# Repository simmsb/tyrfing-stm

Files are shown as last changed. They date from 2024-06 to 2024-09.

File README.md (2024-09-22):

# Hardware and firmware for my flashlight drivers that use stm32L0 processors

<p float="left" align="middle">
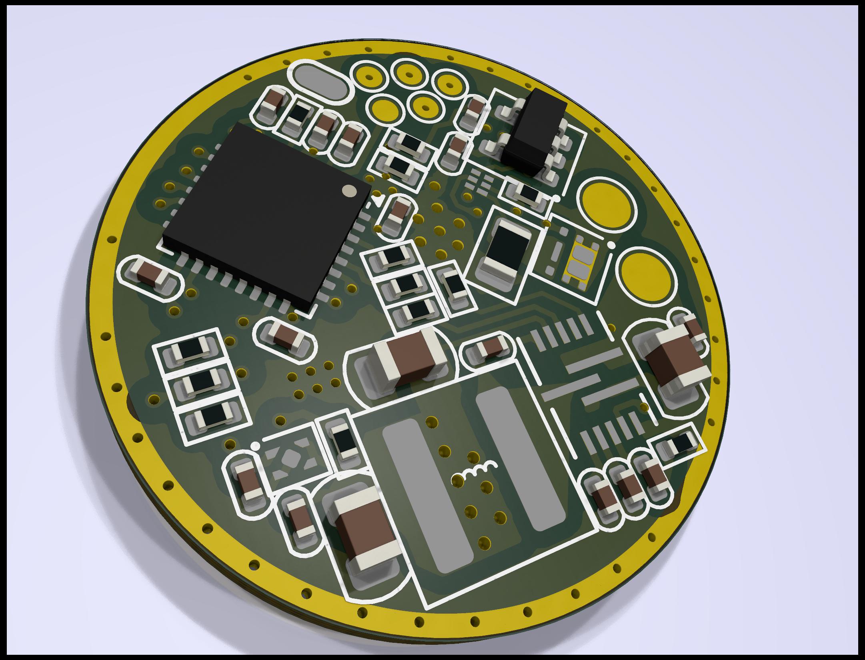
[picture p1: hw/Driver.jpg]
  
  
  
</p>

This repo contains the KiCad files of my self-designed flashlight driver (stm32L0, using a MP3432 boost driver) and the Rust firmware for it.

Mostly based off my [AVR flashlight firmware](https://github.com/simmsb/tyrfing/), also written in Rust.

# Running and flashing

To run with debug logging: `env DEFMT_LOG="debug" cargo run`
To flash a non-debug build: `env DEFMT_LOG="off" cargo run --no-default-features --features default_no_debug --release`

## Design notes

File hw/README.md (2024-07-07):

# Hardware stuff

This folder contains the kicad schematic and layout for the driver, and
`boost.nbt` which is all the potential divider calculations, written in
[numbat](https://github.com/sharkdp/numbat).

# Changelog

- v0: Initial design: had the mistake of using the Rds(on) of a FET as a sense
  resistor... that's a bad idea, don't do it.
  
- v1: Second revision: uses a real sense resistor to measure the high end
  current, and an analog mux to switch between measuring before the low end
  sense resistor, or the high end sense resistor (such that we don't measure
  Rds(on) + Rsense).
  
  I also changed the LDO from 2.5v to 2.8v
  
- v2: Third revision: Adds more current return path vias, but makes the spring
  pad off center (I have no idea if this will work)
  
# Issues I think I still have

1. As of v1 I am not completely happy with the current return path after the
   sense resistors, currently there are vias spammed everywhere possible but I'm
   not sure there's enough. With v2 I added more vias and moved the spring pad
   off center, but that sounds dumb.

# Thanks

This video series:
https://www.youtube.com/playlist?list=PLYK5tmZIBWtEJjwAFE-49hSeELu9zoAmV was a
great help with getting started designing the current controlled boost circuit.

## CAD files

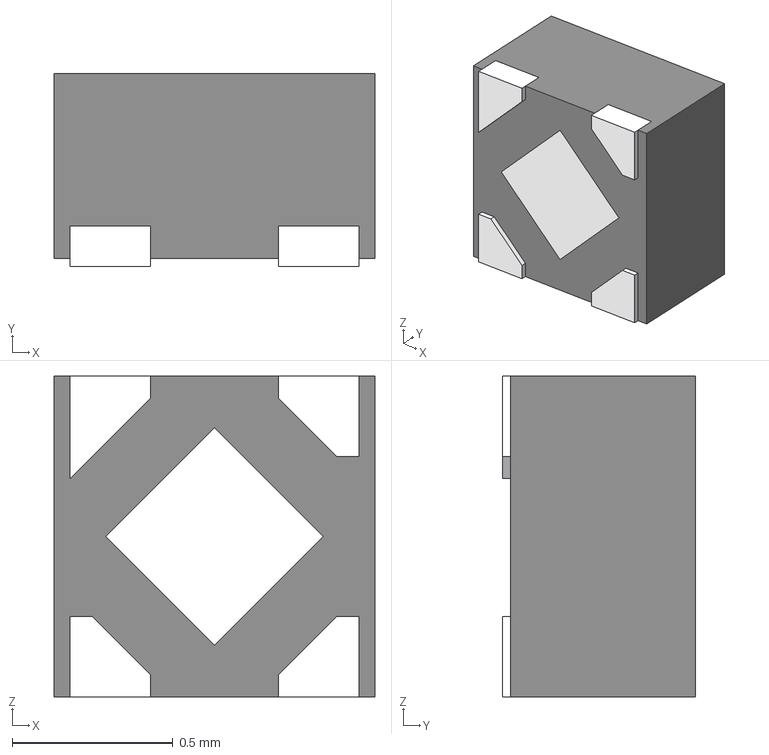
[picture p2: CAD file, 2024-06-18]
hw/components/NCP114AMX330TCG.stp
1.00 x 0.6 x 1.00 mm

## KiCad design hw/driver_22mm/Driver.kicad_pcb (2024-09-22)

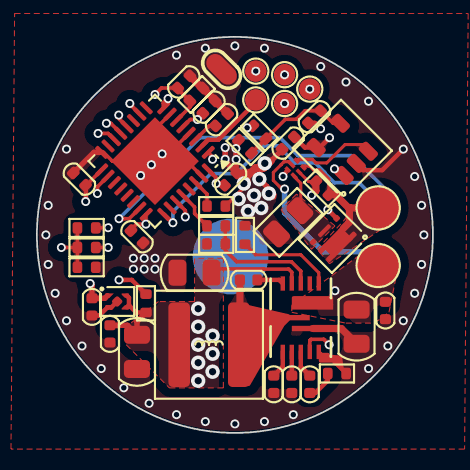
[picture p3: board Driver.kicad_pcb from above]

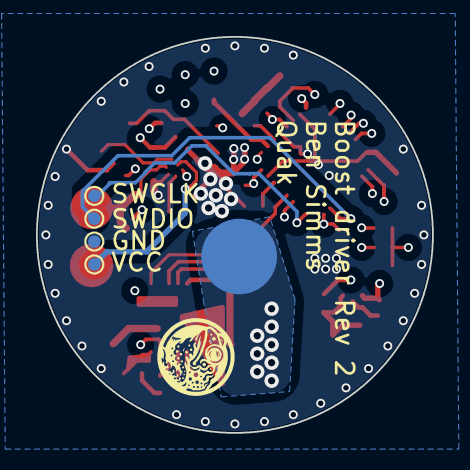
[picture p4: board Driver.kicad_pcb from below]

Board: 4 copper layers, 22.0 x 22.0 mm, 51 parts (4 on the bottom side), 33 nets.

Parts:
C1, C3, C13: 47uF; C_0805_2012Metric
C4, C16, C20: 4.7uF; C_0402_1005Metric
C5: 22nF; C_0402_1005Metric
C6, C8, C10, C14, C15, C17, C18: 100nF; C_0402_1005Metric
C7: 3.3nF; C_0402_1005Metric
C9: 6.8nF; C_0402_1005Metric
C19: 10uF; C_0402_1005Metric
C21: 1nF; C_0402_1005Metric
J1: +LED; TestPoint_Pad_D2.0mm
J2: -LED; TestPoint_Pad_D2.0mm
J3: Button LED; TestPoint_Pad_D1.0mm
J4: Wire GND; TestPoint_Pad_D1.0mm_copy
J5: SWDIO; TestPoint_Pad_D0.7mm
J6: SWCLK; TestPoint_Pad_D0.7mm
J7: GND; TestPoint_Pad_D0.7mm
J8: VCC; TestPoint_Pad_D0.7mm
J9: B; TestPoint_Pad_D1.0mm
J10: R; TestPoint_Pad_D1.0mm
J11: G; TestPoint_Pad_D1.0mm
J12: Button; TestPoint_Pad_D1.0mm
L1: 1.3uH; L_Coilcraft_XAL5030
Q1: Vishay_PowerPAK_SC70-6L_Single
R1: 20k - R_UVLO_BOTTOM; R_0402_1005Metric
R2: 24k - R_UVLO_BOTTOM; R_0402_1005Metric
R3: 285k - R_DAC_TOP; R_0402_1005Metric
R4: 3.3K - R_DAC_BOTTOM1; R_0402_1005Metric
R5: 10m - R_SENSE_MAIN; R_0805_2012Metric
R6: 4R - R_SENSE_HDR; R_0402_1005Metric
R7: 27k; R_0402_1005Metric
R8: 6.8k; R_0402_1005Metric
R9: 750k - R_FB_A; R_0402_1005Metric
R10: 75k - R_FB_B; R_0402_1005Metric
R11: 434k - R_FB_C; R_0402_1005Metric
R12: 10k; R_0402_1005Metric
R13: 1.6M - R_BAT_TOP; R_0402_1005Metric
R14: 3M - R_BAT_BOT; R_0402_1005Metric
U1: MP3431GL-P; QFN-13_MP3431_MNP
U2: OPA333AIDBV; SOT-23-5
U3: STM32L072KBUx; QFN-32-1EP_5x5mm_P0.5mm_EP3.45x3.45mm
U4: NCP114AMX280TCG; UDFN-4-1EP_1x1mm_P0.65mm_EP0.48x0.48mm
U5: XS3A1T3157GSH; XSON6_SOT1202_NEX

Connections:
+BATT: C1.1, C3.1, C16.1, L1.1, R13.1, U1.12 (VIN), U4.3 (EN), U4.4 (IN)
/-LED: J2.1, Q1.1 (D), R6.1, U5.3 (Y1)
/BAT_SENSE: C21.1, R13.2, R14.1, U3.6 (PA0)
/BOOST_EN: R1.1, U3.28 (PB6)
/DAC: R3.1, U3.10 (PA4)
/FB: R9.2, R10.1, R11.2, U1.5 (FB)
/HDR: Q1.3 (G), U3.8 (PA2)
/OPAMP_EN: C8.2, U2.5 (V+), U3.27 (PB5)
/SHUNT_SELECT: U3.1 (PC14), U5.6 (S)
/SWCLK: J6.1, U3.25 (PA14)
/SWDIO: J5.1, U3.23 (PA13)
GND: C1.2, C3.2, C4.2, C5.2, C8.1, C10.2, C13.2, C14.2, C15.1, C16.2, C17.1, C18.1, C19.1, C20.2, C21.2, J4.1, J7.1, R2.2, R4.2, R5.2, R6.2, R7.2, R8.2, R10.2, R12.2, R14.2, U1.6 (AGND), U1.7 (PGND), U2.2 (V-), U3.4 (VSSA), U3.7 (PA1), U3.16 (VSS), U3.31 (VSS), U3.33 (VSS), U4.2 (GND), U4.5 (GND), U5.2 (GND)
unnamed: C7.2, R11.1, U2.1
unnamed: C9.2, R8.1
unnamed: J3.1, U3.2 (PC15)
unnamed: J9.1, U3.14 (PB0)
unnamed: J10.1, U3.12 (PA6)
unnamed: J11.1, U3.13 (PA7)
unnamed: J12.1, U3.18 (PA8)
unnamed: Q1.4 (S), R5.1, U5.1 (Y2)
unnamed: C6.2, U1.13 (BST)
unnamed: C9.1, U1.4 (COMP)
unnamed: R1.2, R2.1, U1.11 (EN)
unnamed: R7.1, U1.9 (ILIM)
unnamed: C5.1, U1.3 (SS)
unnamed: C6.1, L1.2, U1.1 (SW)
unnamed: C4.1, U1.2 (VDD)
unnamed: U2.3 (+), U5.4 (Z)
unnamed: C7.1, R3.2, R4.1, U2.4 (-)
unnamed: R12.1, U3.30 (BOOT0)
unnamed: C14.1, U3.3 (NRST)
VCC: C15.2, C17.2, C18.2, C19.2, C20.1, J8.1, U3.5 (VDDA), U3.17 (VDD), U3.24 (VDD_USB), U3.32 (VDD), U4.1 (OUT), U5.5 (VCC)
VPP: C10.1, C13.1, J1.1, R9.1, U1.8 (VOUT)

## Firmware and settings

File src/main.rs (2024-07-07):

#![feature(type_alias_impl_trait)]
#![feature(impl_trait_in_assoc_type)]
#![feature(impl_trait_in_fn_trait_return)]
#![feature(async_closure)]
#![no_std]
#![no_main]

use defmt::*;
use embassy_stm32::rtc::{Rtc, RtcConfig};
use portable_atomic::AtomicUsize;
use static_cell::{make_static, StaticCell};
// use static_cell::StaticCell;
#[cfg(not(feature = "debug"))]
use panic_reset as _;
#[cfg(feature = "debug")]
use {defmt_rtt as _, panic_probe as _};

mod aux;
mod battery_level;
mod click;
mod monitoring;
mod pins;
mod power;
mod power_curve;
mod state;
mod ui;

#[cfg(feature = "use_maitake_executor")]
mod executor;

static CNT: AtomicUsize = AtomicUsize::new(0);

defmt::timestamp! {"{}", CNT.fetch_add(1, portable_atomic::Ordering::Relaxed) }

#[cfg(feature = "use_maitake_executor")]
mod maitake_stuff {
    use core::future::Future;

    pub struct StaticStorage;

    impl<S: 'static, F: Future + 'static> maitake::task::Storage<S, F> for StaticStorage {
        type StoredTask = &'static mut maitake::task::Task<S, F, StaticStorage>;

        fn into_raw(task: Self::StoredTask) -> core::ptr::NonNull<maitake::task::Task<S, F, Self>> {
            core::ptr::NonNull::from(task)
        }

        fn from_raw(
            mut ptr: core::ptr::NonNull<maitake::task::Task<S, F, Self>>,
        ) -> Self::StoredTask {
            unsafe { ptr.as_mut() }
        }
    }

    impl StaticStorage {
        pub fn allocate<S: maitake::scheduler::Schedule + 'static, F: Future + 'static>(
            fut: F,
        ) -> maitake::task::Task<S, F, Self> {
            maitake::task::Task::new(fut)
        }
    }

    #[repr(transparent)]
    pub struct SurelySend<T>(pub T);
    unsafe impl<T> Send for SurelySend<T> {}
    impl<T: Future> Future for SurelySend<T> {
        type Output = <T as Future>::Output;

        fn poll(
            self: core::pin::Pin<&mut Self>,
            cx: &mut core::task::Context<'_>,
        ) -> core::task::Poll<Self::Output> {
            unsafe { T::poll(core::mem::transmute(self), cx) }
        }
    }
}

#[cfg(feature = "use_maitake_executor")]
#[cortex_m_rt::entry]
fn main() -> ! {
    use maitake_stuff::*;

    macro_rules! spawn {
        ($f:expr) => {{
            let task = make_static!(StaticStorage::allocate(SurelySend($f)));
            task.bind(crate::executor::scheduler());
            crate::executor::scheduler()
                .build_task()
                .spawn_allocated::<StaticStorage, _>(task)
        }};
    }

    info!("Hello world");

    let cfg = embassy_stm32::Config::default();
    let p = embassy_stm32::init(cfg);
    let rtc = Rtc::new(p.RTC, RtcConfig::default());

    static RTC: StaticCell<Rtc> = StaticCell::new();
    let rtc = RTC.init(rtc);

    spawn!(monitoring::monitoring_task(
        pins::take_battery_sense!(p),
        p.ADC1,
        p.IWDG
    ));
    spawn!(power::power_task(
        pins::take_hdr!(p),
        pins::take_opamp_en!(p),
        pins::take_boost_en!(p),
        pins::take_shunt_select!(p),
        p.DAC1,
        pins::take_dac!(p),
        p.PA5
    ));
    spawn!(aux::aux_task(
        p.TIM3,
        pins::take_aux_r!(p),
        pins::take_aux_g!(p),
        pins::take_aux_b!(p)
    ));
    spawn!(click::debouncer_task(
        pins::take_button!(p),
        p.EXTI8,
        pins::take_button_led!(p)
    ));
    spawn!(click::event_generator_task());
    spawn!(ui::torch_ui_task());

    crate::executor::run(rtc);
}

// TODO(ben) add back in support for using the embassy executor, check binary sizes

// #[embassy_executor::task]
// #[embassy_executor::main]
// async fn async_main(spawner: Spawner) {
//     let cfg = embassy_stm32::Config::default();
//     // cfg.rcc.ls = LsConfig::default_lsi();
//     // cfg.rcc.hsi = true;
//     let p = embassy_stm32::init(cfg);

//     // let rtc = Rtc::new(p.RTC, RtcConfig::default());

//     // static RTC: StaticCell<Rtc> = StaticCell::new();
//     // let rtc = RTC.init(rtc);
//     // embassy_stm32::low_power::stop_with_rtc(rtc);

//     info!("Hello World!");

//     spawner.must_spawn(monitoring::monitoring_task(p.PA0, p.ADC1, p.IWDG));
//     spawner.must_spawn(power::power_task(p.PA2, p.PA3, p.DAC1, p.PA4, p.PA5));
//     spawner.must_spawn(aux::aux_task(p.TIM3, p.PA6, p.PA7, p.PB0));
//     spawner.must_spawn(click::debouncer_task(p.PA8, p.EXTI8));
//     spawner.must_spawn(click::event_generator_task());
//     spawner.must_spawn(ui::torch_ui_task());

//     spawner.must_spawn(vary_light());
// }

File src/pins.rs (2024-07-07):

macro_rules! define_pin {
    ($name:ident, $p:ident) => {
        #[allow(unused)]
        macro_rules! $name {
            () => {
                ::embassy_stm32::peripherals::$p
            };
        }

        ::paste::paste! {
            #[allow(unused)]
            macro_rules! [<take_ $name>] {
                ($pins:expr) => {
                    $pins.$p
                }
            }

            #[allow(unused)]
            pub(crate) use [<take_ $name>];
        }

        #[allow(unused)]
        pub(crate) use $name;
    };
}

define_pin!(battery_sense, PA0);
define_pin!(hdr, PA2);

#[cfg(feature = "board_dev")]
define_pin!(en, PA3);
#[cfg(feature = "board_v0")]
define_pin!(en, PB5);

#[cfg(feature = "board_v1")]
define_pin!(opamp_en, PB5);
#[cfg(feature = "board_v1")]
define_pin!(boost_en, PB6);
#[cfg(feature = "board_v1")]
define_pin!(shunt_select, PC14);

define_pin!(dac, PA4);
define_pin!(aux_r, PA6);
define_pin!(aux_g, PA7);
define_pin!(aux_b, PB0);
define_pin!(button_led, PC15);
define_pin!(button, PA8);

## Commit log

2024-06-02 More information
    [Driver.kicad_pcb, Driver.kicad_sch]
2024-06-11 More accurate battery percentage
    Linearly interpolate given control points
2024-06-12 Fade out when depressing switch in lockout mode
2024-06-18 Driver v2 changes
    [Driver.kicad_pcb, Driver.kicad_sch, NCP114AMX330TCG.stp]
2024-07-07 Update battery voltage divider
2024-09-22 Push changes
    [Driver.kicad_pcb]
